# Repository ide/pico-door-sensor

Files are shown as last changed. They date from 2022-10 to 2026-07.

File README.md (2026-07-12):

# Pico W Garage Door Sensor

Get notified when your garage door's been left open. This sensor uses the Raspberry Pi Pico W and CircuitPython and requires Home Assistant with MQTT set up.

## Hardware

The Raspberry Pi Pico W is powered by a standard 5V USB Micro B power supply.

GPIO 22 is pulled up to 3.3V with a 10K ohm resistor. This external pull-up resistor is stronger than the Pico's internal pull-up resistors that can be configured on the GPIO pins and helps reduce the effects of ESD on the long wires from the Pico to the reed switch. GPIO 22 also has an optional 1K ohm current-limiting resistor (even a lower value like 100 ohms is fine) to protect it from shorting to ground in case it is misconfigured as an output pin.

Why GPIO 22? It doesn't have any alternative function like SPI, I2C, or ADC. This leaves all the other GPIO pins free if you want to attach a screen or other peripherals to your Pico.

You could add a small capacitor to debounce the reed switch in hardware but this project debounces the GPIO pin in software.

### Schematic

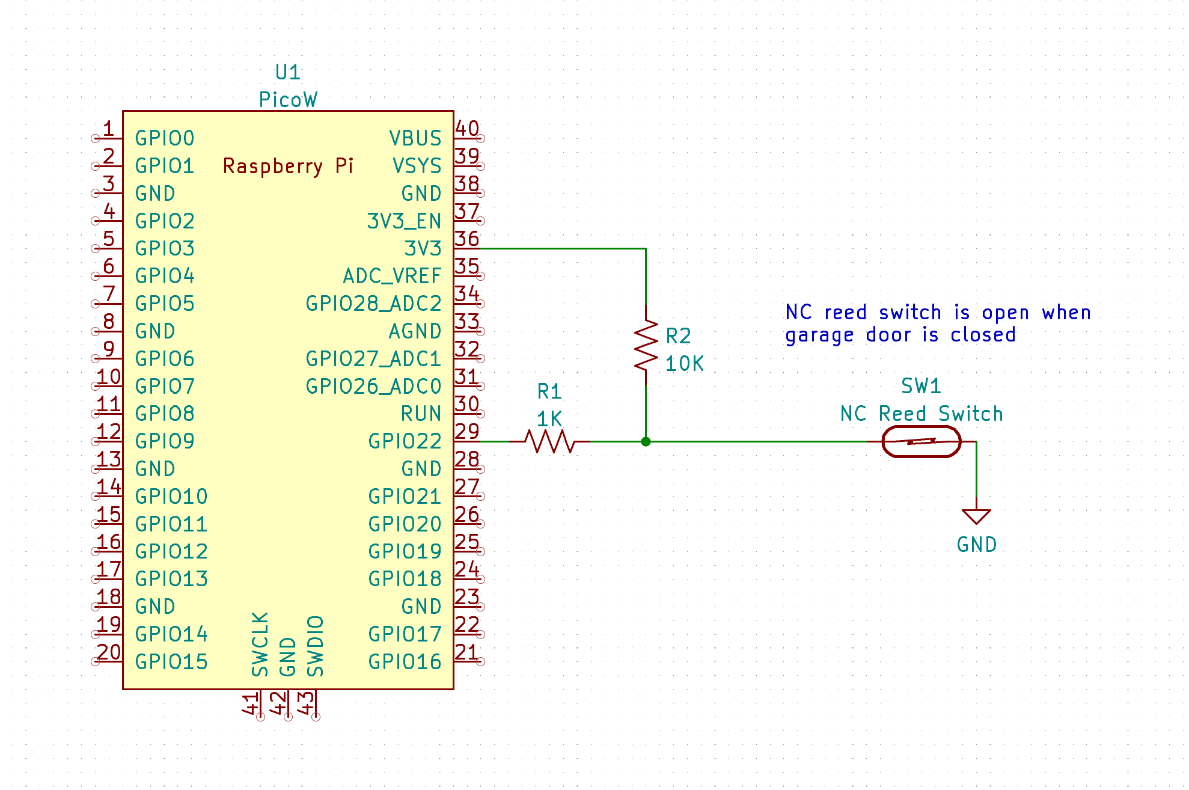
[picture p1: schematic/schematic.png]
Schematic


### BOM

| Reference | Part description | Example part # |
|---|---|---|
| R1 | 1K ohm current-limiting resistor (optional) | [CF14JT1K00](https://www.digikey.com/en/products/detail/stackpole-electronics-inc/CF14JT1K00/1741314) |
| R2 | 1K ohm pull-up resistor | [CF14JT10K0](https://www.digikey.com/en/products/detail/stackpole-electronics-inc/CF14JT10K0/1741265) |
| SW1 | SPST NC reed switch | [59140-4-S-02-F](https://www.digikey.com/en/products/detail/littelfuse-inc/59140-4-S-02-F/4780045) and [57140-000](https://www.digikey.com/en/products/detail/littelfuse-inc/57140-000/43978) |
| U1 | Raspberry Pi Pico W | [04025C104KAT2A](https://www.digikey.com/en/products/detail/kyocera-avx/04025C104KAT2A/6564238) |
| | USB Micro B power supply (5V@1A is plenty) | |
| | Stranded copper wire, 22-24 AWG (long enough to reach your garage door from the Pico and back) | |
## Software

Install CircuitPython 10 on your Pico W using [a .uf2 file](https://circuitpython.org/board/raspberry_pi_pico_w/) from the CircuitPython website.

Create settings.toml under src or directly in your CIRCUITPY drive and define the following environment variables:
```toml
CIRCUITPY_WIFI_SSID = "your Wi-Fi access point's name"
CIRCUITPY_WIFI_PASSWORD = "your Wi-Fi password"

MQTT_HOSTNAME = "your MQTT broker's hostname"
MQTT_USERNAME = "the username to use with your MQTT broker"
MQTT_PASSWORD = "the password to use with your MQTT broker"

WIFI_HOSTNAME = "garagesensor"
```

There are convenient scripts under the `scripts` directory for deploying software to your Pico W and connecting to its REPL. Only macOS is supported.

### MiniMQTT fork

This project uses a fork of Adafruit_CircuitPython_MiniMQTT with [PR #259](https://github.com/adafruit/Adafruit_CircuitPython_MiniMQTT/pull/259), which allows `MQTT.loop()` timeouts shorter than the socket timeout, so the main loop's wait between reed switch checks is not coupled to the socket timeout. The compiled .mpy files are committed under `vendor/lib` and `scripts/deploy` copies them to the device. The other libraries in requirements.txt are still installed with circup.

The committed .mpy files were compiled from [`28bfda9`](https://github.com/ide/Adafruit_CircuitPython_MiniMQTT/commit/28bfda91ad284db04ac91869ced3c6a5aa4517a4) on the fork's `loop-timeout-independent-of-socket-timeout` branch using CircuitPython's mpy-cross 10.2.1, and load on any CircuitPython 10.x since the bytecode format only changes between major versions. To recompile them after updating the fork or moving to a new CircuitPython major, download CircuitPython's mpy-cross (not MicroPython's, which emits an incompatible format) from the [mpy-cross builds on S3](https://adafruit-circuit-python.s3.amazonaws.com/index.html?prefix=bin/mpy-cross/) and run it on each .py file in the fork's `adafruit_minimqtt` package. When the PR merges upstream, delete `vendor/` and restore the `adafruit_minimqtt` entry in requirements.txt.

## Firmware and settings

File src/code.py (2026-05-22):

import binascii
import os
import time
import traceback

import board
import digitalio
import mdns
import microcontroller
import socketpool
import supervisor
import wifi

import adafruit_debouncer
import adafruit_logging
import adafruit_minimqtt.adafruit_minimqtt as adafruit_minimqtt

from logging import create_logger
from mqtt import (
    publish_availability_online_message,
    publish_homeassistant_discovery_message,
    publish_sensor_state_message,
    set_availability_offline_will,
)


def main(logger: adafruit_logging.Logger) -> None:
    led = digitalio.DigitalInOut(board.LED)
    led.switch_to_output()

    switch_io = digitalio.DigitalInOut(board.GP22)
    # GPIO 22 has a pull-up resistor so we don't pull it up in code
    switch_io.switch_to_input()
    switch = adafruit_debouncer.Debouncer(switch_io)

    # The switch is open when the door is closed
    led.value = not switch.value

    # Connect to the Wi-Fi network
    logger.info("Connecting to the local Wi-Fi network...")
    wifi.radio.hostname = os.getenv("WIFI_HOSTNAME")
    wifi.radio.connect(
        os.getenv("CIRCUITPY_WIFI_SSID"), os.getenv("CIRCUITPY_WIFI_PASSWORD")
    )
    logger.info(
        "Connected to the local network: IP address = %s, router = %s, DNS server %s",
        wifi.radio.ipv4_address,
        wifi.radio.ipv4_gateway,
        wifi.radio.ipv4_dns,
    )
    pool = socketpool.SocketPool(wifi.radio)

    # Advertise a local hostname with mDNS for pinging the device
    mdns_server = mdns.Server(wifi.radio)
    mdns_server.hostname = wifi.radio.hostname
    logger.info("Advertised mDNS hostname: %s", mdns_server.hostname)

    mqtt_device_id = binascii.hexlify(microcontroller.cpu.uid).decode("utf-8")
    mqtt_state_topic = f"door/{mqtt_device_id}/state"
    mqtt_availability_topic = f"door/{mqtt_device_id}/availability"

    # Connect to the MQTT broker. Register the will before connecting so the broker delivers our
    # "offline" availability when this device disappears without a clean disconnect (loss of Wi-Fi,
    # power, or keepalive timeout). Home Assistant uses the will to mark the binary_sensor entity
    # unavailable.
    logger.info("Connecting to the MQTT broker...")
    # Use a stable client ID derived from the CPU UID so that when the device reconnects after a
    # crash, the broker takes over the previous session as a normal disconnect [MQTT-3.1.4-2] rather
    # than firing the prior session's will. Without this, adafruit_minimqtt picks a new random
    # client ID each boot and the broker eventually times out the orphaned session and publishes
    # "offline" to the availability topic, overwriting the new session's "online".
    mqtt = adafruit_minimqtt.MQTT(
        broker=os.getenv("MQTT_HOSTNAME"),
        username=os.getenv("MQTT_USERNAME"),
        password=os.getenv("MQTT_PASSWORD"),
        is_ssl=False,
        socket_pool=pool,
        client_id=mqtt_device_id,
    )
    mqtt.logger = logger
    set_availability_offline_will(mqtt, mqtt_availability_topic)
    mqtt.connect()
    logger.info("Connected to the MQTT broker")

    # Announce we're online and our current state. Both messages are retained so Home Assistant sees
    # them on its next subscribe even if the device is restarting while HA is reconnecting.
    publish_availability_online_message(mqtt, mqtt_availability_topic)
    publish_homeassistant_discovery_message(
        mqtt, mqtt_device_id, mqtt_state_topic, mqtt_availability_topic
    )
    is_door_open = not switch.value
    publish_sensor_state_message(mqtt, mqtt_state_topic, is_door_open)
    logger.info(
        "Advertised Home Assistant discovery message and current door state (%s)",
        "open" if is_door_open else "closed",
    )

    logger.info("Monitoring door sensor...")
    while True:
        switch.update()
        mqtt.loop(timeout=0.05)

        if switch.rose or switch.fell:
            is_door_open = not switch.value
            logger.info(
                "Detected the door open" if is_door_open else "Detected the door closed"
            )
            led.value = is_door_open
            publish_sensor_state_message(mqtt, mqtt_state_topic, is_door_open)


logger = create_logger()

try:
    main(logger)
except Exception as exception:
    logger.critical("%s", "".join(traceback.format_exception(exception, limit=8)))
    time.sleep(10)
    if supervisor.runtime.usb_connected:
        supervisor.reload()
    else:
        microcontroller.reset()

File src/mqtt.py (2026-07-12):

import json


def publish_homeassistant_discovery_message(
    mqtt, device_id: str, state_topic: str, availability_topic: str
) -> None:
    mqtt.publish(
        f"homeassistant/binary_sensor/{device_id}/config",
        json.dumps(
            {
                "unique_id": device_id,
                "name": "Garage Door",
                "default_entity_id": "binary_sensor.garage_door",
                "device": {
                    "name": "Door Sensor",
                    "identifiers": [device_id],
                    "model": "Raspberry Pi Pico W Door Sensor",
                    "manufacturer": "Raspberry Pi",
                    "suggested_area": "garage",
                },
                "device_class": "garage_door",
                "state_topic": state_topic,
                # Home Assistant accepts the strings "online" and "offline" as the availability
                # payloads by default, so we don't need to specify "payload_available" and
                # "payload_not_available" fields in this discovery message.
                "availability_topic": availability_topic,
            }
        ),
        retain=True,
        qos=1,
    )


def publish_sensor_state_message(mqtt, state_topic: str, sensor_state: bool) -> None:
    mqtt.publish(
        state_topic,
        "ON" if sensor_state else "OFF",
        retain=True,
        qos=1,
    )


def publish_availability_online_message(mqtt, availability_topic: str) -> None:
    mqtt.publish(availability_topic, "online", retain=True, qos=1)


def set_availability_offline_will(mqtt, availability_topic: str) -> None:
    mqtt.will_set(availability_topic, "offline", retain=True, qos=1)

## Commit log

2022-10-12 Add readme with BOM and a KiCad project with a schematic
    [Pico W Garage Door Sensor.kicad_sch]
2023-02-18 Add an IRQ-based sensor, web server skeleton, and development scripts
2023-02-19 Add a CircuitPython implementation and development scripts
2023-03-05 Add small site with a service worker, make MQTT optional, use HTTPS (will abandon)
    - A small website registers a service worker and subscribes to push notifications
    - MQTT is now optional, set `MQTT_ENABLED = 1` in settings.toml to opt in
    - Configured the web server to use HTTPS. However, even with a small 1024-bit RSA certificate, performance is too slow (~10 seconds per response) and the service worker doesn't even load. Going to deploy this to the cloud instead eventually, and have the Pico just receive push subscriptions and send push notifications.
    [code.py]
2025-06-27 Update dependencies (upgrading to CircuitPython 9.2.8)
2025-06-27 Update deploy script to replicate circup's device-finding logic
    circup made the device search function private.
2025-06-27 Don't clear settings.toml on the device
2026-05-07 Track device availability in Home Assistant
    Why
    ===
    Before this change, Home Assistant always showed the door sensor as available, regardless of whether the device was actually reachable. If the Pico lost power or Wi-Fi, HA kept reporting the last kno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
    How
    ===
    On boot we register a retained `"offline"` last will against `door/<id>/availability`, then publish a retained `"online"` to the same topic after `mqtt.connect()`. The discovery payload now includes 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
2026-05-07 Bump dependencies and document CircuitPython 10
2026-05-15 Use bare raise to preserve traceback
2026-05-22 Set MQTT delay to 50ms
    This uses a patched version of MiniMQTT that allows arbitrarily low timeouts. This will make the sensor more responsive.
2026-07-12 Replace deprecated object_id with default_entity_id in HA discovery
    Home Assistant deprecated the `object_id` option in MQTT discovery configs and warns that it will stop working after HA Core 2026.4. The opener firmware in pico-garage-opener already migrated to `default_entity_id` and its retained config has been working in production on HA 2026.7.
    The entity registry pins the existing `binary_sensor.garage_door` entity by `unique_id`, so this only matters when the entity is discovered fresh, such as after a registry loss or on a rebuilt HA instance. Without the fix, a fresh discovery could assign a different entity id and silently break the garage cover package, which hard-codes `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
    [mqtt.py]
2026-07-12 Switch to MiniMQTT fork allowing short loop() timeouts
    Upstream MiniMQTT couples `MQTT.loop()` to the socket timeout: the loop cannot wait less than `socket_timeout` (1 second by default), and newer upstream releases raise `ValueError` when asked to. Lowering the global socket timeout only partly helps because broker connection setup then warns when it takes longer than the socket timeout. So each pass through the main loop could block well past the intended 50 ms before the reed switch was checked again and a door transition published.
    adafruit/Adafruit_CircuitPython_MiniMQTT#259 (authored from this fork) decouples the loop timeout from the socket timeout using socket readiness pol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
